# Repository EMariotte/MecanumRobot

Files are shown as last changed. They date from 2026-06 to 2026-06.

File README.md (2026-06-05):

# Robot Mecanum 4WD — Semillero

Proyecto de construcción de un robot con ruedas Mecanum desarrollado en el **Semillero de Robótica**, como trabajo conjunto entre **Breyner** (aprendiz) y su facilitador, con apoyo de **Claude (Anthropic)** como asistente de ingeniería.

## Plataforma

| Parámetro | Valor |
|---|---|
| MCU | ESP8266 NodeMCU v1 |
| Framework | Arduino (vía PlatformIO) |
| Comunicación | ESP-NOW (peer-to-peer, sin router) |
| Motores | 4× DC con ruedas Mecanum |
| Driver | 2× TB6612FNG |
| Batería | 2S 18650 — 7.4V nominal |

## Estado del proyecto

| Paso | Descripción | Estado |
|---|---|---|
| 1 | `test_74hc595` — ESP8266 + 74HC595 + 8 LEDs | ✅ Completado |
| 2 | `test_tb6612` — TB6612 ×2 + motores reales | 🔄 En curso |
| 3 | `test_i2c` — MPU-6050 + VL53L0X ×2 | ⬜ Pendiente |
| 4 | `test_espnow` — Comunicación inalámbrica | ⬜ Pendiente |
| 5 | `mecanum_main` — Firmware final integrado | ⬜ Pendiente |

## Mapa de pines

| GPIO | Pin NodeMCU | Función |
|---|---|---|
| GPIO4 | D2 | SDA I2C |
| GPIO5 | D1 | SCL I2C |
| GPIO12 | D6 | PWM Motor FL |
| GPIO13 | D7 | PWM Motor FR |
| GPIO14 | D5 | PWM Motor RL |
| GPIO15 | D8 | PWM Motor RR |
| GPIO0 | D3 | DS — data 74HC595 |
| GPIO2 | D4 | SHCP — clock 74HC595 |
| GPIO10 | SD3 | STCP — latch 74HC595 |
| GPIO16 | D0 | STBY TB6612 ×2 |
| GPIO1 | TX | XSHUT VL53L0X #1 |
| GPIO3 | RX | XSHUT VL53L0X #2 |
| ADC0 | A0 | Monitor batería |

## Estructura del repositorio

```
MecanumRobot/
├── firmware/
│   ├── test_74hc595/          ← Paso 1 (completado)
│   ├── test_tb6612/           ← Paso 2 (en curso)
│   ├── test_i2c/
│   └── mecanum_main/
├── hardware/
│   ├── fritzing/
│   │   ├── mecanum_robot.fzz  ← esquemático editable (Fritzing)
│   │   └── mecanum_robot.png  ← imagen para visualizar en GitHub
│   └── bom/
├── docs/
└── platformio.ini
```

## Cómo usar

1. Abrir el proyecto en VS Code con la extensión PlatformIO
2. El `platformio.ini` apunta al firmware activo via `src_dir`
3. Para cambiar de subsistema editar `src_dir` en `platformio.ini`
4. Compilar y subir con el botón **Build / Upload** de PlatformIO

---

*Proyecto semillero — Construcción incremental por subsistemas*

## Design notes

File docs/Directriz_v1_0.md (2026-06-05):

# Directriz de Proyecto — Robot Mecanum 4WD
**v1.0 — Mayo 2026**

## Estado de fases

| Fase | Descripción | Estado |
|---|---|---|
| Fase 1 | Arquitectura del sistema | ✅ COMPLETADA |
| Fase 2 | Subsistema de potencia | ✅ COMPLETADA |
| Fase 3 | Control de motores | ✅ COMPLETADA |
| Fase 4 | Sensores I2C | ✅ COMPLETADA |
| Fase 5 | Diseño de PCB | ✅ COMPLETADA |
| Fase 6 | Firmware ESP-NOW | 🔄 EN CURSO |

---

## Objetivo general

Diseñar y construir un robot móvil omnidireccional basado en 4 ruedas mecanum impresas en 3D, controlado de forma inalámbrica mediante ESP-NOW, con una PCB personalizada que integra todos los subsistemas de potencia, control de motores y sensado.

---

## Plataforma física

### Ruedas mecanum
- Modelo: Thingiverse thing:1358552 — Jonah_Innoart
- Diámetro: 44mm / Ancho: 21.4mm
- Eje: 3mm tipo D (flat shaft)
- Rodillos: pines de costura 27mm
- Configuración: FL, FR, RL, RR

### Motores
- Pololu Metal Gear Motor 75:1
- Voltaje nominal: 6V–9V (operación a 7.4V)
- Corriente típica: ~400mA por motor
- Corriente de stall: ~1.2A por motor
- Eje: D-shaft 3mm

---

## Arquitectura — decisiones definitivas

### Microcontrolador
- ESP8266 NodeMCU v1
- Voltaje lógico: 3.3V
- Comunicación: ESP-NOW (peer-to-peer, sin router)
- Expansión DIR: 74HC595 shift register

### Alimentación
- Pack 18650 — 2S (7.4V nominal)
- BMS 2S 20A
- Conector: XT30 macho
- Regulación lógica: AMS1117-3.3V

### Control de motores
- 2× TB6612FNG
- VM: 7.4V desde batería
- VCC lógica: 3.3V (sin level shifter)
- STBY: GPIO16 compartido + pull-up 10k

### Sensores
- IMU: MPU-6050 — I2C 0x68
- ToF #1: VL53L0X — I2C 0x30 (reasignada), XSHUT←GPIO1
- ToF #2: VL53L0X — I2C 0x29 (default), XSHUT←GPIO3

---

## Protecciones de hardware (obligatorias)

| Protección | Componente | Valor |
|---|---|---|
| Polaridad invertida | MOSFET-P AO3401 | SOT-23 |
| Sobrecorriente | Polyfuse MF-R600 | 6A |
| Transitorios EMI | TVS P6KE10A | clamp 10V |
| Desacople VM | C4, C5 | 100µF + 100nF |
| Desacople motores | C6–C13 | 100nF ×8 |
| Pull-up I2C | R6, R7 | 4.7kΩ |
| Pull-up STBY | R3 | 10kΩ a 3V3 |

---

## Especificaciones PCB

- Dimensiones: 100mm × 80mm (máximo)
- Capas: 2 (Top: componentes + señal / Bottom: plano GND)
- Pistas VBAT/VM: 2.5mm mínimo
- Pistas GND potencia: 3.0mm / plano completo
- Pistas 3V3: 0.8mm
- Pistas señal: 0.3mm
- Montaje: M3 ×4 esquinas, standoffs 10mm

### Zonas
- Zona superior: potencia (XT30, fusible, MOSFET-P, TVS, AMS1117)
- Zona media-izquierda: TB6612 ×2 + conectores JST motores
- Zona media-derecha: ESP8266 NodeMCU + 74HC595
- Zona inferior: MPU-6050 + VL53L0X ×2 + conectores I2C

---

## BOM consolidada

| Ref | Componente | Modelo | Package | Cant |
|-----|---|---|---|---|
| U1 | Regulador 3.3V | AMS1117-3.3 | SOT-223 | 1 |
| U2, U3 | Driver motor | TB6612FNG | SOP-24 | 2 |
| U4 | Shift register | 74HC595 | SOP-16 | 1 |
| U5 | IMU 6DOF | MPU-6050 | QFN-24 | 1 |
| U6, U7 | ToF sensor | VL53L0X | LGA-12 | 2 |
| Q1 | MOSFET-P | AO3401 | SOT-23 | 1 |
| D1 | Diodo TVS | P6KE10A | DO-15 | 1 |
| F1 | Polyfuse 6A | MF-R600 | 1812 SMD | 1 |
| C1,C4,C5 | Electrolítico | 100µF/16V | SMD D6.3 | 3 |
| C2,C3,C6-C15 | Cerámico | 100nF/16V | 0805 | 12 |
| C16,C17 | Cerámico | 10µF/10V | 0805 | 2 |
| R1 | Resistencia | 10kΩ | 0805 | 1 |
| R2 | Resistencia | 100kΩ | 0805 | 1 |
| R3 | Pull-up STBY | 10kΩ | 0805 | 1 |
| R4 | Divisor bat. | 100kΩ | 0805 | 1 |
| R5 | Divisor bat. | 13kΩ | 0805 | 1 |
| R6, R7 | Pull-up I2C | 4.7kΩ | 0805 | 2 |
| R8, R9 | Resistencia LED | 330Ω | 0805 | 2 |
| LED1 | LED rojo | — | 0805 | 1 |
| LED2 | LED verde | — | 0805 | 1 |
| SW1 | Interruptor | KCD1 | Through hole | 1 |
| J1 | Conector bat. | XT30 macho | Through hole | 1 |
| J2-J5 | Conector motor | JST-PH 2pin | Through hole | 4 |
| J6 | Header I2C | JST-SH 4pin | SMD | 1 |
| J7, J8 | Conector ToF | JST-SH 6pin | SMD | 2 |

---

## Fuera de alcance v1.0

- Navegación autónoma / SLAM
- Encoders / odometría
- Pantalla en el robot
- Cargador de batería integrado en PCB

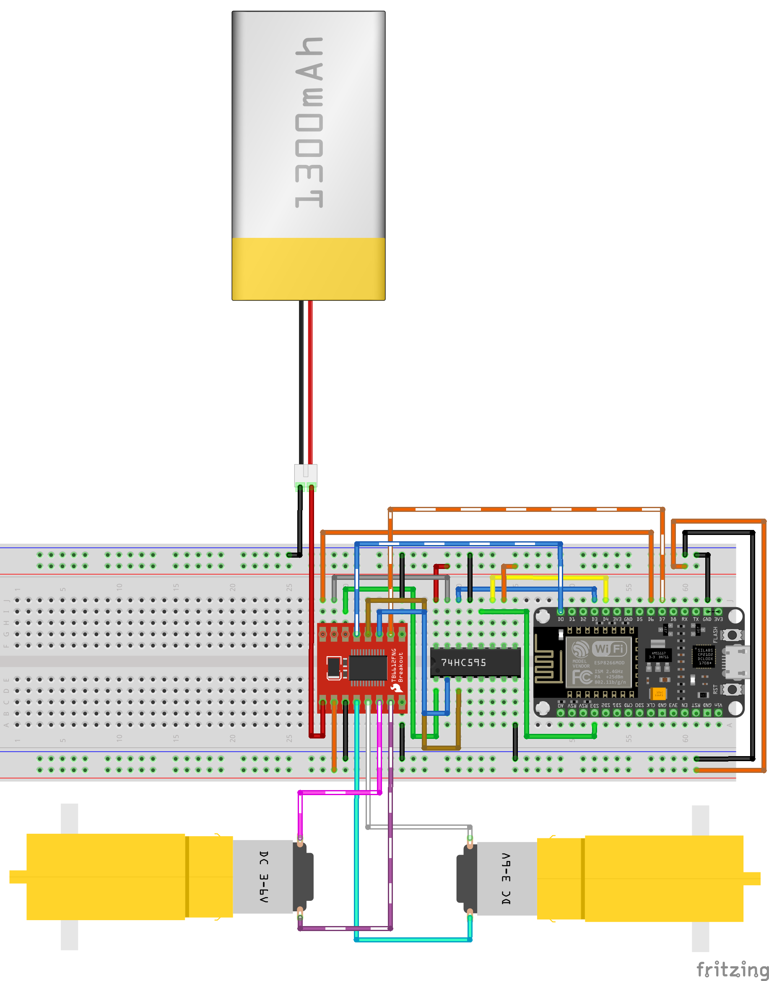
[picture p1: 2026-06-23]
hardware/fritzing/RobotMecanum_bb.png

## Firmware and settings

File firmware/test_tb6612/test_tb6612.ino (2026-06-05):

#include <Arduino.h>

// ============================================================
//  PRUEBA TB6612 + 74HC595 + ESP8266 NodeMCU
//  Robot Mecanum 4WD — Fase 6 / Step 2
//  Ciclo automático: adelante → stop → atrás → stop
// ============================================================

// --- 74HC595 ---
#define DS_PIN   0   // GPIO0 / D3
#define SHCP_PIN 2   // GPIO2 / D4
#define STCP_PIN 10  // GPIO10 / SD3 — latch (independiente de STBY)

// --- TB6612 enable ---
#define STBY_PIN 16  // GPIO16 / D0 — STBY ambos TB6612, siempre HIGH

// --- PWM de los 4 motores ---
#define PWM_FL  12   // D6 — Frontal Izquierdo
#define PWM_FR  13   // D7 — Frontal Derecho
#define PWM_RL  14   // D5 — Trasero Izquierdo
#define PWM_RR  15   // D8 — Trasero Derecho

// --- Bytes de dirección ---
#define DIR_ADELANTE  0x55   // 01010101 — todos adelante
#define DIR_ATRAS     0xAA   // 10101010 — todos atras
#define DIR_STOP      0x00   // coast

#define VELOCIDAD     180    // 0–255

// ------------------------------------------------------------
void shiftWrite(byte data) {
  digitalWrite(STCP_PIN, LOW);
  shiftOut(DS_PIN, SHCP_PIN, MSBFIRST, data);
  digitalWrite(STCP_PIN, HIGH);
}

void setPWM(int spd) {
  analogWrite(PWM_FL, spd);
  analogWrite(PWM_FR, spd);
  analogWrite(PWM_RL, spd);
  analogWrite(PWM_RR, spd);
}

void adelante(int spd, int ms) {
  shiftWrite(DIR_ADELANTE);
  setPWM(spd);
  delay(ms);
}

void atras(int spd, int ms) {
  shiftWrite(DIR_ATRAS);
  setPWM(spd);
  delay(ms);
}

void parar(int ms) {
  setPWM(0);
  shiftWrite(DIR_STOP);
  delay(ms);
}

// ------------------------------------------------------------
void setup() {
  Serial.begin(115200);
  pinMode(DS_PIN,   OUTPUT);
  pinMode(SHCP_PIN, OUTPUT);
  pinMode(STCP_PIN, OUTPUT);
  pinMode(STBY_PIN, OUTPUT);
  digitalWrite(STBY_PIN, HIGH);   // habilitar TB6612 desde el inicio
  pinMode(PWM_FL, OUTPUT);
  pinMode(PWM_FR, OUTPUT);
  pinMode(PWM_RL, OUTPUT);
  pinMode(PWM_RR, OUTPUT);

  parar(500);
  Serial.println("=== TEST 4 RUEDAS ===");
}

// ------------------------------------------------------------
void loop() {
  Serial.println(">> Adelante 2s");
  adelante(VELOCIDAD, 2000);

  Serial.println(">> Stop 1s");
  parar(1000);

  Serial.println(">> Atras 2s");
  atras(VELOCIDAD, 2000);

  Serial.println(">> Stop 1s");
  parar(1000);
}

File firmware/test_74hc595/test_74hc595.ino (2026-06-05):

#include <Arduino.h>

// ============================================================
//  PRUEBA 74HC595 + ESP8266 NodeMCU
//  Robot Mecanum 4WD — Fase 6 / Step 1
//  Verifica que shiftOut() llega correcto a Q0-Q7
// ============================================================

#define DS_PIN   0   // GPIO0 / D3 — data serial
#define SHCP_PIN 2   // GPIO2 / D4 — clock
#define STCP_PIN 10  // GPIO10 / SD3 — latch (separado de STBY)

// ------------------------------------------------------------
//  Envía un byte al 74HC595
//  bit7 → Q7 ... bit0 → Q0
// ------------------------------------------------------------
void shiftWrite(byte data) {
  digitalWrite(STCP_PIN, LOW);
  shiftOut(DS_PIN, SHCP_PIN, MSBFIRST, data);
  digitalWrite(STCP_PIN, HIGH);
}

// ------------------------------------------------------------
//  Setup
// ------------------------------------------------------------
void setup() {
  Serial.begin(115200);
  pinMode(DS_PIN,   OUTPUT);
  pinMode(SHCP_PIN, OUTPUT);
  pinMode(STCP_PIN, OUTPUT);

  shiftWrite(0x00);  // apaga todo al inicio
  Serial.println("\n=== TEST 74HC595 ===");
  Serial.println("Comandos: 0-9 patrones, 'x' valor hex manual");
}

// ------------------------------------------------------------
//  Loop — espera comando por Serial Monitor
// ------------------------------------------------------------
void loop() {
  if (!Serial.available()) return;

  char cmd = Serial.read();

  switch (cmd) {

    case '0':
      shiftWrite(0x00);
      Serial.println("[0] Todo apagado        00000000");
      break;

    case '1':
      shiftWrite(0xFF);
      Serial.println("[1] Todo encendido      11111111");
      break;

    case '2':
      // Todos los motores ADELANTE
      // FL: Q0=1,Q1=0 | FR: Q2=1,Q3=0 | RL: Q4=1,Q5=0 | RR: Q6=1,Q7=0
      shiftWrite(0b01010101);
      Serial.println("[2] Todos ADELANTE      01010101  (0x55)");
      break;

    case '3':
      // Todos los motores ATRAS
      // FL: Q0=0,Q1=1 | FR: Q2=0,Q3=1 | RL: Q4=0,Q5=1 | RR: Q6=0,Q7=1
      shiftWrite(0b10101010);
      Serial.println("[3] Todos ATRAS         10101010  (0xAA)");
      break;

    case '4':
      // Solo Q0 — bit más bajo
      shiftWrite(0b00000001);
      Serial.println("[4] Solo Q0             00000001");
      break;

    case '5':
      // Solo Q7 — bit más alto
      shiftWrite(0b10000000);
      Serial.println("[5] Solo Q7             10000000");
      break;

    case '6':
      // Barrer Q0→Q7 uno por uno (ver el LED viajar)
      Serial.println("[6] Barrido Q0 → Q7 ...");
      for (int i = 0; i < 8; i++) {
        shiftWrite(1 << i);
        Serial.print("    Q"); Serial.print(i);
        Serial.print(" encendido  ");
        printBits(1 << i);
        delay(400);
      }
      shiftWrite(0x00);
      Serial.println("    fin barrido");
      break;

    case '7':
      // Parpadeo 5 veces — todos
      Serial.println("[7] Parpadeo x5 ...");
      for (int i = 0; i < 5; i++) {
        shiftWrite(0xFF); delay(250);
        shiftWrite(0x00); delay(250);
      }
      Serial.println("    fin parpadeo");
      break;

    case '8':
      // Pares encendidos (Q0,Q2,Q4,Q6) — AIN1 de los 4 motores
      shiftWrite(0b01010101);
      Serial.println("[8] AIN1 todos          01010101");
      break;

    case '9':
      // Impares encendidos (Q1,Q3,Q5,Q7) — AIN2 de los 4 motores
      shiftWrite(0b10101010);
      Serial.println("[9] AIN2 todos          10101010");
      break;

    case 'x':
    case 'X': {
      // Leer valor hex manual: escribe xAB y envía 0xAB
      delay(20);
      String hexStr = Serial.readStringUntil('\n');
      hexStr.trim();
      byte val = (byte) strtol(hexStr.c_str(), NULL, 16);
      shiftWrite(val);
      Serial.print("[x] Manual 0x");
      if (val < 16) Serial.print("0");
      Serial.print(val, HEX);
      Serial.print("  ");
      printBits(val);
      break;
    }

    case '\r':
    case '\n':
      break;  // ignorar saltos de línea

    default:
      Serial.println("Comandos disponibles:");
      Serial.println("  0 → todo apagado");
      Serial.println("  1 → todo encendido");
      Serial.println("  2 → todos motores ADELANTE");
      Serial.println("  3 → todos motores ATRAS");
      Serial.println("  4 → solo Q0");
      Serial.println("  5 → solo Q7");
      Serial.println("  6 → barrido Q0→Q7");
      Serial.println("  7 → parpadeo x5");
      Serial.println("  8 → solo pines AIN1 (Q0,Q2,Q4,Q6)");
      Serial.println("  9 → solo pines AIN2 (Q1,Q3,Q5,Q7)");
      Serial.println("  xAB → enviar valor hex manual (ej: xAB, xFF, x0F)");
      break;
  }
}

// ------------------------------------------------------------
//  Imprime byte como cadena de 8 bits en Serial
// ------------------------------------------------------------
void printBits(byte val) {
  for (int i = 7; i >= 0; i--) {
    Serial.print(bitRead(val, i));
  }
  Serial.println();
}

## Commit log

2026-06-05 Inicio proyecto Robot Mecanum 4WD — Semillero
    - Fase 1 completada: test_74hc595 verificado con 8 LEDs
    - Fase 2 en curso: test_tb6612 (4 motores via TB6612 + 74HC595)
    - Corrección de pines: GPIO10/SD3 → STCP, GPIO16/D0 → solo STBY
    - CLAUDE.md con arquitectura completa del sistema
2026-06-23 Agregar hardware: Fritzing + KiCad v1.1 (parcial, AUX.kicad_sch pendiente)
    - Esquematico Fritzing (fzz + PNG breadboard view)
    - KiCad v1.1: PCB, esquematicos MCU/MOTOR/PWR/SENSOR, libs
    - AUX.kicad_sch bloqueado por KiCad abierto, commit siguiente
    - .gitignore: excluir carpeta .history de KiCad
    [MCU.kicad_sch, MOTOR.kicad_sch, MecanumRobot_v1.1.kicad_pcb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]
2026-06-23 Excluir AUX.kicad_sch del repo hasta completar el esquematico
